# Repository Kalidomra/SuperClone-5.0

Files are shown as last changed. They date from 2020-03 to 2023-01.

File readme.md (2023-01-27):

# **SuperClone 5.0**

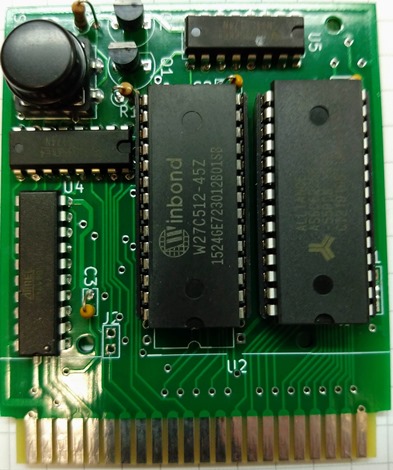
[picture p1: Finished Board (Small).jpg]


This is a clone of the Super Snapshot v5 hardware. All of the traces are close to the original and it will fit in the same case as an original. It uses an Atmel ATF16V8B in the place of the original PAL. I have also tried a ATF16V8C, but it did not work. All of the parts, including the Atmel are interchangeable with an original. I have also included the WinCUPL source files and a DigiKey bill of materials. The EEPROM is not available at DigiKey. I bought one from Ebay. 

The following parts will need to programmed:

  ATF16V8B-15PU --> This needs to be programmed with the include .jed file. 

  W27C512-45Z --> Programmed with any available Super Snapshot v5 ROM. See: https://rr.pokefinder.org/wiki/Super_Snapshot

It will also work with a larger 32 pin EEPROM like the W27C010-70 or W27C020-70. This is only required for a larger rom file like the SnappyROM:
https://github.com/adrianglz64/snappyrom

The EPROM used must be relatively fast (70ns or faster seems to work fine.) Some of the cheap, clone, UV erasable 27C512 EPROMS I tried did not work. I suspect they were remarked and in reality a slower part.

I have also included a 3d printable case. However, Hackup has made great case available here: https://www.thingiverse.com/thing:4623905

The original PCB was setup for 8K Ram, the clone is also defaulted this way. In order to use the 32K ram you need to cut the trace betrween pin 1 and 2 on J1 and then jumper pin 2 and 3 on J1.

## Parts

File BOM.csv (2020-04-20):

Part | Part Number | Description | Digikey
U1 | HM6264 8k / HM62256 32k | On HM6264 - Pin 26 is CS2 - Pull High Pin 1 is Not Connected On HM62256 - Pin 26 is A13 Pin 1 is A14 Need to modify J1 to use HM62256. | 1450-1033-ND (32K) OR 1450-1036-ND (8K)
U2 | 27512 EPROM (Used 32pin Socket) | Used 32 pin socket to enable future 128K upgrade 27C512 (64k) or 27C010 (128k) - W27C512-45Z (Ebay)
U3 | 16L8 PAL | Use ATF16V8B-15PU as substitute. | ATF16V8B-15PU-ND
U4 | 74LS174 |  | 296-3664-5-ND
U5 | 74LS174 |  | 296-3664-5-ND
Q1 | PN2222A |  | PN2222ATACT-ND
Q2 | PN2222A |  | PN2222ATACT-ND
R1 | 1.5K 1/4W |  | CF14JT1K50CT-ND
R2 | 1.5K 1/4W |  | CF14JT1K50CT-ND
C1 | 100nF |  | 1109PHCT-ND
C2 | 100nF |  | 1109PHCT-ND
C3 | 100nF |  | 1109PHCT-ND
SW1 | ADTS24NV |  | 679-2374-ND
CAP | AKTSC22K | Switch Cap - 13mm dia vs 9.9mm for original | 679-2315-ND

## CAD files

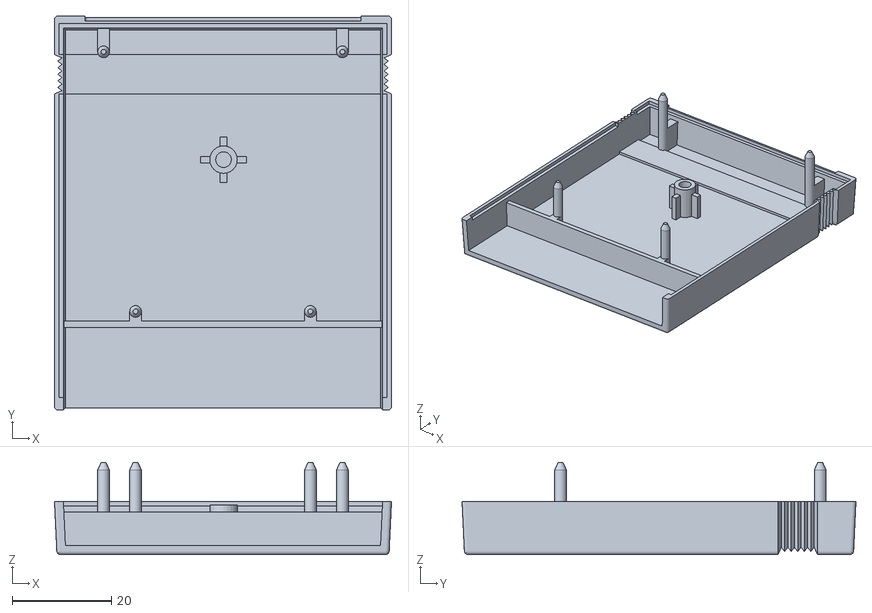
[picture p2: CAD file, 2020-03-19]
Case Model/Bottom(v0.1).stl
67.8 x 79.2 x 18.5

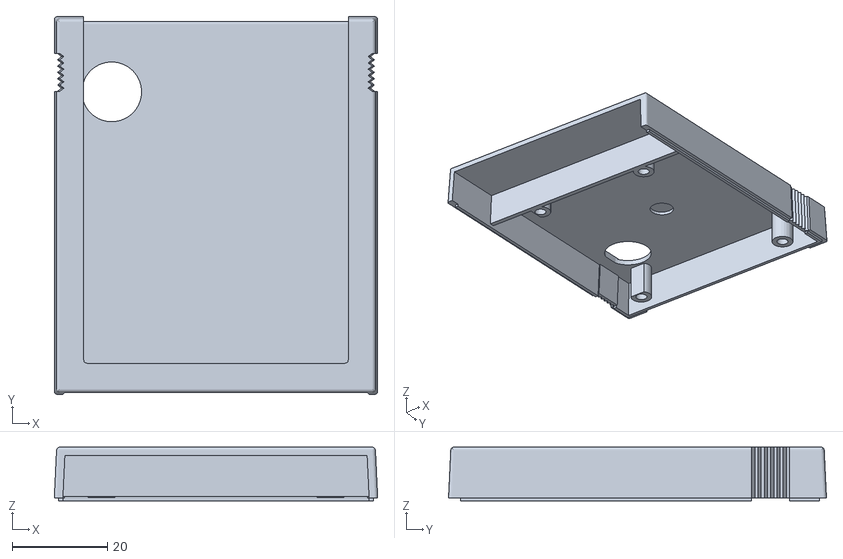
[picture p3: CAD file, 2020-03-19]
Case Model/Top(v0.1).stl
67.8 x 79.2 x 11.3

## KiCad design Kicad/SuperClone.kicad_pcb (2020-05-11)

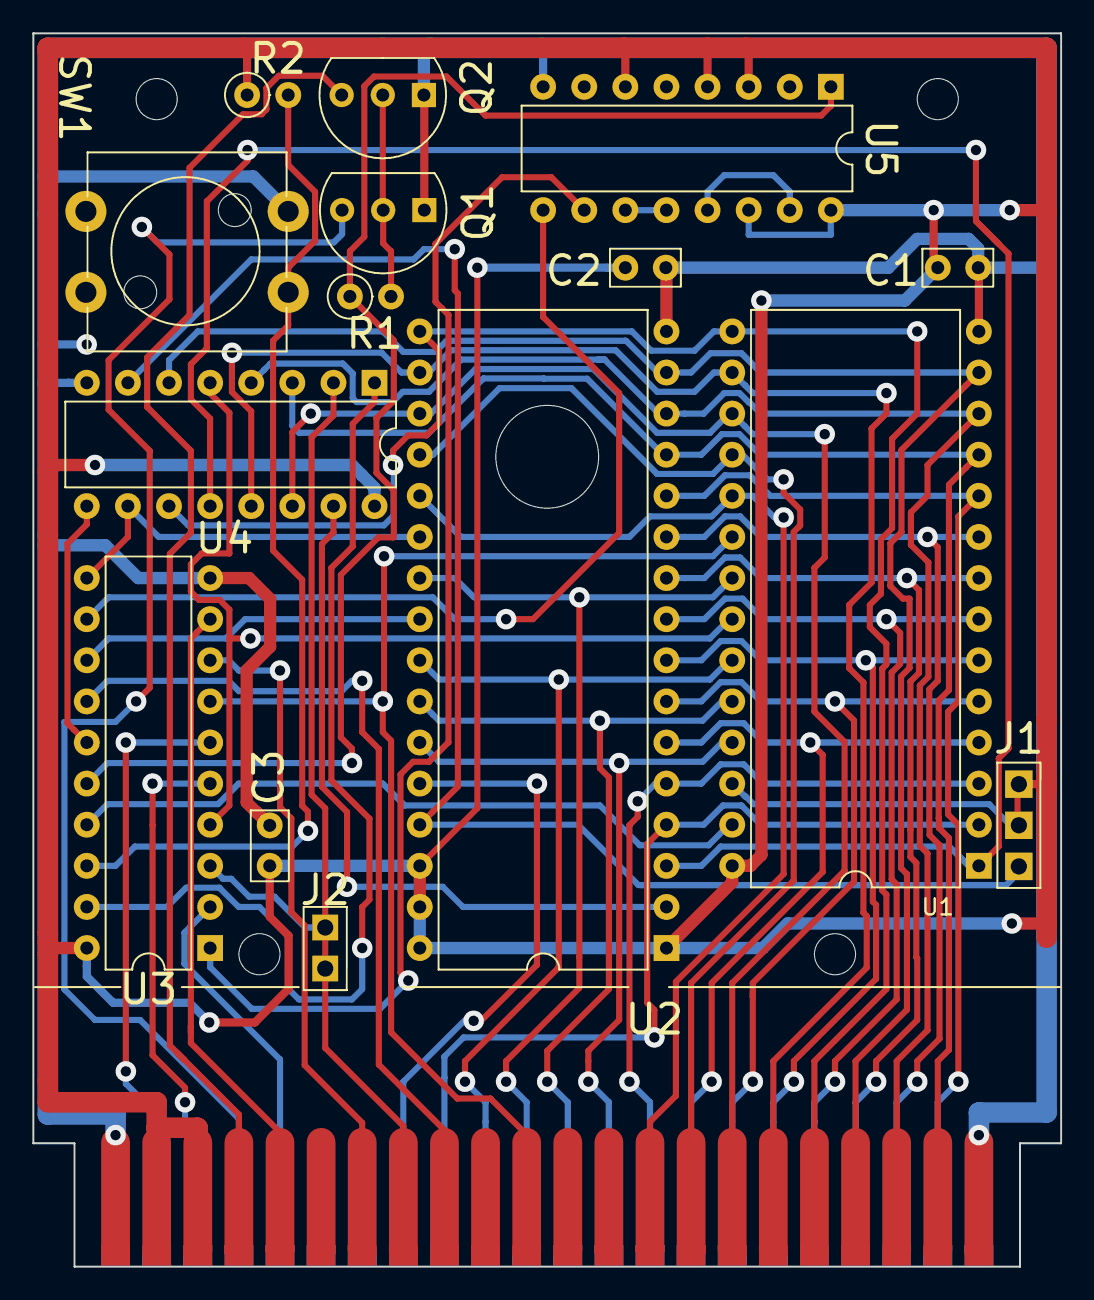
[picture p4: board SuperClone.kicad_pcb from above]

Board: 2 copper layers, 63.5 x 76.2 mm, 16 parts (0 on the bottom side), 50 nets.

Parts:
C1, C2, C3: 100nF; C_Disc_D3.4mm_W2.1mm_P2.50mm
EXP1: EXPANSION_PORT-SuperClone; expansion_port
J1: Jumper_3_Bridged12; PinHeader_1x03_P2.54mm_Vertical
J2: Jumper_2_Bridged; PinHeader_1x02_P2.54mm_Vertical
Q1, Q2: PN2222A; TO-92L_Inline_Wide
R1, R2: 1.5K; R_Axial_DIN0207_L6.3mm_D2.5mm_P2.54mm_Vertical
SW1: SW_DIP_x01; SW_PUSH-12mm
U1: HM62256; DIP-28_W15.24mm_Socket
U2: 27C010; DIP-32_W15.24mm_Socket
U3: PAL16L8; DIP-20_W7.62mm_Socket
U4, U5: 74LS174; DIP-16_W7.62mm_Socket

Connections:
+5V: C1.1, C2.1, C3.1, EXP1.2, EXP1.3, J1.1, J1.2, R2.1, U1.26, U1.28, U2.1, U2.30, U2.31, U2.32, U3.20, U4.16, U5.3, U5.4, U5.6, U5.14, U5.16
/A0: EXP1.Y, U1.10, U2.12
/A1: EXP1.X, U1.9, U2.11
/A2: EXP1.W, U1.8, U2.10
/A3: EXP1.V, U1.7, U2.9
/A4: EXP1.U, U1.6, U2.8
/A5: EXP1.T, U1.5, U2.7
/A6: EXP1.S, U1.4, U2.6
/A7: EXP1.R, U1.3, U2.5
/A8: EXP1.P, U1.25, U2.27
/A9: EXP1.N, U1.24, U2.26
/A10: EXP1.M, U1.21, U2.23
/A11: EXP1.L, U1.23, U2.25
/A12: EXP1.K, U1.2, U2.4
/A13: EXP1.J, U2.28
/BA14: J1.3, U2.29, U4.7
/BA15: U1.1, U2.3, U4.12
/BA16: U2.2, U4.15
/CLKa: U3.12, U5.9
/CLKb: U3.15, U4.9
/CLRa: R1.1, U3.16, U5.1
/CLRb: U3.19, U4.1
/D0: EXP1.21, U1.11, U2.13, U4.3
/D1: EXP1.20, U1.12, U2.14, U4.4
/D2: EXP1.19, U1.13, U2.15, U4.6
/D3: EXP1.18, U1.15, U2.17, U4.11
/D4: EXP1.17, U1.16, U2.18, U4.13
/D5: EXP1.16, U1.17, U2.19, U4.14
/D6: EXP1.15, U1.18, U2.20
/D7: EXP1.14, U1.19, U2.21
/Delay: U3.1, U5.10
/Exrom: EXP1.9, U3.14
/Game: EXP1.8, J2.1, J2.2, U3.3, U4.2
/IOe: EXP1.7, U3.8
/IRQ: EXP1.4, Q2.3
/NMI: EXP1.D, Q1.3
/Phi2: EXP1.E, U3.2
/RW: EXP1.5, U3.9
/RamE: U1.22, U3.4, U4.5
/RamW: U1.27, U3.17
/Reset: EXP1.C, U3.5
/RomE: U2.22, U3.11, U4.10
/RomH: EXP1.B, U3.6
/RomL: EXP1.11, U1.20, U3.7
/RomOE: U2.24, U3.13
/key: R2.2, SW1.1, U3.18
GND: C1.2, C2.2, C3.2, EXP1.1, EXP1.22, EXP1.A, EXP1.Z, Q1.1, Q2.1, SW1.2, U1.14, U2.16, U3.10, U4.8, U5.8
unnamed: Q1.2, Q2.2, R1.2
unnamed: U5.11, U5.12
unnamed: U5.13, U5.15

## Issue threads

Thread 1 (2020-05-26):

Information on programmers/programming

HVR88, 2020-05-26:
Please add some information on sourcing programmer hardware for use with the chips in the BOM that will work on modern hardware. Likely needs to be USB.

I'd love to build one of these as the parts sourcing and soldering look fairly basic, but programming the PROMs is likely to be a challenge for anyone not already set up with dedicated hardware/software to do so.

Kalidomra, 2020-05-31:
I use a TOP3000 USB programmer to program both the .JED file to the ATF16V8B-15PU and the Super Snapshot .BIN file to the W27C512-45Z. These are available on Ebay or AliExpress. A TL866 programmer is also showing that it supports both of theses devices. The TL866 seems to be cheaper, but I have not tested it.

HVR88, 2020-06-15:
Have you by any chance tried PCBWay for the PCB build?

Kalidomra, 2020-06-15:
No. I have used jlcpcb.com

Closed 2020-06-15.

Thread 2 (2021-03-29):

Please consider adding a license

Low012, 2021-03-29:
At the moment it is not clear under which license the content of this repository may be shared. Adding a license would help.

I am aware that it may be problematic to add a license for the design of the PCB since it is derived from a commercial product, but maybe it is possible to add a license which is limited explicitly to the files in this repository.

Closed 2022-04-21.

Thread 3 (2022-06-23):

8K / 32K RAM, Jumper configuration

MarkusPlehn, 2022-06-23:
I am not sure about the correct Jumper config for 8 or 32 K RAM.
Could you specify this please?

Thanks for this nice Replica 🙂

Kalidomra, 2022-06-23:
J1 Config:

8K RAM:    1-2
32K RAM:  2-3

Pin 1 of the Jumper is close to the "J1" text and Pin 3 is closest to the cartridge port.

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

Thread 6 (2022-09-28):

Snappy V531 NTSC ROM not working on SuperClone board.

Robert-Di-Benedetto, 2022-09-28:
Flashed an AT29C010A-12PC 128KB ROM with Snappy V531 NTSC binary.  Flash was verified to correctly match the binary.  Also examined a dump to manually verify.

Installed in a known good working SuperClone board that has SS V5.22 ROM.  Boots to a black screen.  Tried with both 8K and 32K RAM configurations.  Reinstalled original V5.22 ROM and all is working fine.

Also submitting this issue on the Snappy (Adrian Gonzalez) GIT area.

Kalidomra, 2022-09-28:
I have not tested either the new binary or a AT29C010A-12PC. However, looking at the datasheet it is a 120ns part. It may be too slow for the SuperClone. The W27C512-45Z that I have used is 45ns. That also may explain why some of the re-labeled EPROMs I have from Aliexpress do not work, they maybe too slow.

Robert-Di-Benedetto, 2022-09-28:
Ok.  I will order a few other ROMs and give them a try.  M27C2001-10F1 (256K 100ns), 27C010-70 (128K 70ns) and 27C040-70 (512K 70ns).  I'll circle back when I have the test results.  In the meantime, if you have any other ROM suggestions, I'm happy to try them if I can source them.

Robert-Di-Benedetto, 2022-09-28:
I've just ordered a W27C020-70Z as well.  I'll double confirm when it arrives.  It will be good to have a list of multiple eprom options so sourcing can be easier.

Scyllinice, 2022-09-29:
For clarity, I posted on the Snappy issue as well that I did update my eprom to the Snappy rom and put it in my SuperClone board and it worked right away.

Robert-Di-Benedetto, 2022-10-02:
So far I have confirmed the following:
M27C2001-10F1 does NOT work
AM27HB010-70DC (128k) DOES work
AM27C040-70DC (512k) DOES work

Still waiting on delivery of W27C020-70Z

Robert-Di-Benedetto, 2022-10-08:
I have now double-confirmed that W27C020-70Z also works.  So we now have 3 confirmed working ROMs.

Kalidomra, 2023-01-27:
The Windbond W27C010-70 and W27E010-70 work. You need to change the 28 pin socket to a 32 pin. The new snappy rom also works. It is 128k so it will only work with a 32 pin chip.

Closed 2023-01-27.

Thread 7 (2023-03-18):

PLA Issue

thegoat1973, 2023-03-18:
I built a couple of these with 15ns GAL and 45ns WinBond EEPROMs.  The cartridge starts up fine and exits to Basic, however after pressing the freeze button and resuming the program it crashes. If I switch out the PLA to a GAL PLA I don't have this issue, and I've tried on 3 different machines with the same results. Anyone else have this issue??

Kalidomra, 2023-03-21:
What is the part number of the GAL you are using?

thegoat1973, 2023-03-22:
Sorry, my initial post wasn't very clear on that. The machine that the cartridge works on has a GAL based PLA chip replacement in it. If I use a stock MOS PLA in the machine the SS5 crashes on Resume. I've tried this on 2 breadbin C64 and a newer model 64C. The GAL PLA is a PLA replacement based on the GAL 20V8B and is meant as a drop in replacement for dead PLA chips in C64's.

Kalidomra, 2023-03-22:
Are you sure the MOS PLA works?  It could also be the EEPROM you used. I have had issues with a few different ones.

thegoat1973, 2023-03-23:
The machines all work with the stock PLA's. I have an original SS4 which works correctly in them as well as a SS5 image on a 1541 Ultimate II+ that works flawlessly. I've tried 4 different EEPROMS and 2 different GAL's in the PCB with same result. I'm starting to think the problem may be with the PCB's I ordered from PCBWay. I'll have to have a closer look at them.

thegoat1973, 2023-03-26:
I took a closer look at the PCB and everything looks to be okay on the board. What type of EEPROM have you had success with and which ones have not worked?

Kalidomra, 2023-03-27:
W27C512-45Z
W27C010-70 or W27C020-70

Closed 2024-01-25.
